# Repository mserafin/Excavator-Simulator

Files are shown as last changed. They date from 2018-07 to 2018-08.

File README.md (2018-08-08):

Excavator simulator
=====

It is an excavator simulator integrated with the game `DIG IT! - A Digger Simulator`, but can be easily integrated with another game.

[Link to the video](https://youtu.be/R2LVpZUrTIc)

The code was created for the needs of my eight-year-old son who is a huge fan of construction machinery.

The whole architecture was based on the Arduino Pro Micro microcontroller, which has a USB 2.0 interface thanks to which the driver can be seen as a USB device. In my case, this allowed me to simulate pressing a combination of keys on the keyboard.

The simulator has been equipped with: four analog joysticks that realistically reflect the physics of machine motion,
ignition switch to run the board, 2x16 LCD display with I2C interfac, which in the first assumption was supposed to show speed and basic parameters, but the game manufacturer did not foresee the possibility of writing modifications. The simulator has also been equipped with six Arcade buttons with backlight to control additional functions, eg turning on the radio, lights, etc. Arduino does not have enough pins, so the simulator has two PCF8574 integrated circuits, thanks to which we obtained an additional 16 digital pins.

Sketch

## License

This project is licensed under the MIT License - see the [LICENSE](LICENSE.md) file for details

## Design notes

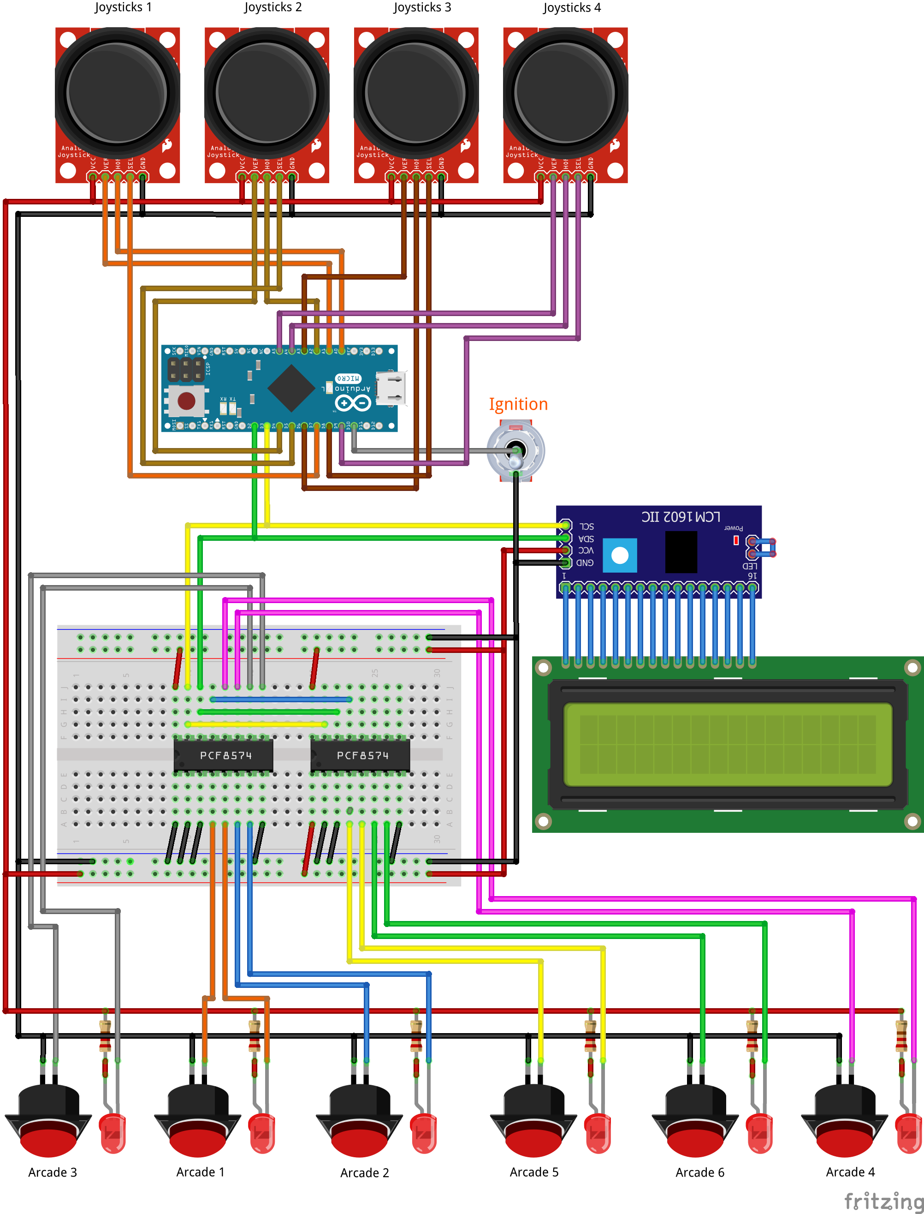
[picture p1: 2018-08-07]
sketch.png

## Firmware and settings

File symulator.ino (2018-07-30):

#include <Keyboard.h>
#include "Expander.h"
#include "Ignition.h"
#include "Display.h"
#include "Axis.h"
#include "Button.h"
#include "ButtonArray.h"
#include "AxisArray.h"
//#include "Mouse.h"

const bool DEBUG = 0;

const int IGNITION_PIN = 10;
const int RANGE_AXIS = 10;
const int COUNT_AXLES = 8;
const int COUNT_SWITCHES = 10;
const int COUNT_LEDS = 6;
const unsigned long RESPONSE_DELAY = 500UL;
const unsigned long DISPLAY_DELAY = 1500UL;

bool buttonAxisA1IsActive = false;
bool buttonAxisA2IsActive = false;

unsigned long lastDisplayMillis;

Display lcd;
Expander expander1;
Expander expander2;
Ignition ignition;
ButtonArray buttonArray = ButtonArray(COUNT_SWITCHES);
AxisArray axisArray = AxisArray(COUNT_AXLES);

enum Simulator {
  EXCAVATORS,
  FARMING
};

struct ShortcutsAxis {
  char KEY_JOYSTICK_UP;
  char KEY_JOYSTICK_DOWN;
  char KEY_JOYSTICK_LEFT;
  char KEY_JOYSTICK_RIGHT;
  char KEY_JOYSTICK_SWITCH;
};

struct Joysticks {
  ShortcutsAxis Joysticks1;
  ShortcutsAxis Joysticks2;
  ShortcutsAxis Joysticks3;
  ShortcutsAxis Joysticks4;
} Mapping[2] = {
  {
    {KEY_UP_ARROW, KEY_DOWN_ARROW, KEY_LEFT_ARROW, KEY_RIGHT_ARROW},
    {'a', 'q', 'k', 'i'},
    {'w', 's'},
    {'e', 'd', 'r', 'f'}
  },
  {
    {'w', 's', 'a', 'd'}
  }
};

struct DebugAxis {
  String axisName;
  int axisValue;
};

Simulator simulator = EXCAVATORS;

void setup() {
  setupIgnition();
  setupExpander();
  setupArcadeLed();
  setupOutput();
  setupDisplay();
  setupSwitch();
  setupAxis();
}

void loop() {
  inspectIgnition();
  inspectExpander();
  inspectSwitch();
  inspectAxis();

  if (checkDisplayUpdate()) {
    lcd.display("Symulator!", true, 0, 0);
    lcd.display("Milosz", false, 0, 1);
  }
}

void setupIgnition() {
  ignition.begin(IGNITION_PIN, ignitionOnChangeStatus);
}

void setupExpander() {
  expander1.begin(0x20);
  expander2.begin(0x21);
}

void setupArcadeLed() {
  struct Config {
    byte pin;
    Expander *expander;
  } leds[COUNT_LEDS] = {
    {1, &expander1},
    {3, &expander1},
    {5, &expander1},
    {7, &expander1},
    {1, &expander2},
    {3, &expander2}
  };

  for (byte i = 0; i < COUNT_LEDS; i++) {
    Config &config = leds[i];
    config.expander->pinMode(config.pin, OUTPUT);
    config.expander->digitalWrite(config.pin, HIGH);
  }
}

void setupOutput() {
  if (!DEBUG) {
    Keyboard.begin();
    //Mouse.begin();
    return;
  }

  while (!Serial);
  Serial.begin(115200);
}

void setupDisplay() {
  lcd.begin(16, 2);
}

void setupSwitch() {
  struct Config {
    byte pin;
    Expander *expander;
    void (*action)(bool state);
  } buttons[COUNT_SWITCHES] = {
    {5, NULL, &SwitchJoystickD5},
    {7, NULL, &SwitchJoystickD7},
    {8, NULL, &SwitchJoystickD8},
    {9, NULL, &SwitchJoystickD9},
    {0, &expander1, &SwitchArcadeE1D0},
    {2, &expander1, &SwitchArcadeE1D2},
    {4, &expander1, &SwitchArcadeE1D4},
    {6, &expander1, &SwitchArcadeE1D6},
    {0, &expander2, &SwitchArcadeE2D0},
    {2, &expander2, &SwitchArcadeE2D2}
  };

  for (byte i = 0; i < COUNT_SWITCHES; i++) {
    Config &config = buttons[i];
    Button button;

    if (config.expander != NULL) {
      button.begin(config.pin, config.expander);
    } else {
      button.begin(config.pin);
    }
    button.onClick = *config.action;
    buttonArray.append(button);
  }
}

void setupAxis() {
  struct Config {
    byte pin;
    void (*action)(int key);
  } Axises[COUNT_AXLES] = {
    {A0, &AxisA0},
    {A1, &AxisA1},
    {A2, &AxisA3},
    {A3, &AxisA4},
    {A4, &AxisA7},
    {A5, &AxisA6},
    {A6, &AxisA2},
    {A7, &AxisA5}
  };

  for (byte i = 0; i < COUNT_AXLES; i++) {
    Config &config = Axises[i];
    Axis axis = Axis(RANGE_AXIS, RESPONSE_DELAY);
    axis.begin(config.pin, *config.action);
    axisArray.append(axis);
  }
}

void inspectIgnition() {
  ignition.refresh();
}

void inspectExpander() {
  expander1.refresh();
  expander2.refresh();
}

void inspectSwitch() {
  buttonArray.refresh();
}

void inspectAxis() {
  axisArray.refresh();
}

void ignitionOnChangeStatus() {
  lcd.display("Wlacz zaplon!");
}

bool checkDisplayUpdate() {
  unsigned long currentMillis = millis();
  if ((currentMillis - lastDisplayMillis) > DISPLAY_DELAY) {
    lastDisplayMillis = currentMillis;
    return true;
  }
  return false;
}

void AxisA0(int reading) {
  DebugAxis debug = {__PRETTY_FUNCTION__, reading};
  ShortcutsAxis shortcut = Mapping[simulator].Joysticks1;
  char key;

  switch (simulator) {
    case EXCAVATORS:
      key = reading > 0 ? shortcut.KEY_JOYSTICK_RIGHT : shortcut.KEY_JOYSTICK_LEFT;

      if (buttonAxisA1IsActive) {
        append(KEY_LEFT_CTRL, false, debug);
      }
      append(key, true, debug);
      break;
    case FARMING:
      key = reading > 0 ? shortcut.KEY_JOYSTICK_LEFT : shortcut.KEY_JOYSTICK_RIGHT;
      append(key, true, debug);
      break;
  }
}

void AxisA1(int reading) {
  DebugAxis debug = {__PRETTY_FUNCTION__, reading};
  ShortcutsAxis shortcut = Mapping[simulator].Joysticks1;

  switch (simulator) {
    case EXCAVATORS:
    case FARMING:
      char key = reading > 0 ? shortcut.KEY_JOYSTICK_UP : shortcut.KEY_JOYSTICK_DOWN;
      append(key, true, debug);
      break;
  }
}

void AxisA2(int reading) {
  DebugAxis debug = {__PRETTY_FUNCTION__, reading};
  ShortcutsAxis shortcut = Mapping[simulator].Joysticks2;

  if (simulator == EXCAVATORS) {
    char key = reading > 0 ? shortcut.KEY_JOYSTICK_UP : shortcut.KEY_JOYSTICK_DOWN;

    if (buttonAxisA2IsActive) {
      key = reading > 0 ? shortcut.KEY_JOYSTICK_LEFT : shortcut.KEY_JOYSTICK_RIGHT;
    }

    append(key, true, debug);
    return;
  }
}

void AxisA3(int reading) {
  DebugAxis debug = {__PRETTY_FUNCTION__, reading};
  ShortcutsAxis shortcut = Mapping[simulator].Joysticks2;
  //append('x', debug);
}

void AxisA4(int reading) {
  DebugAxis debug = {__PRETTY_FUNCTION__, reading};
  ShortcutsAxis shortcut = Mapping[simulator].Joysticks3;

  if (simulator == EXCAVATORS) {
    char key = reading > 0 ? shortcut.KEY_JOYSTICK_UP : shortcut.KEY_JOYSTICK_DOWN;
    append(key, true, debug);
    return;
  }
}

void AxisA5(int reading) {
  DebugAxis debug = {__PRETTY_FUNCTION__, reading};
  ShortcutsAxis shortcut = Mapping[simulator].Joysticks3;
  //append('x', debug);
}

void AxisA6(int reading) {
  DebugAxis debug = {__PRETTY_FUNCTION__, reading};
  ShortcutsAxis shortcut = Mapping[simulator].Joysticks4;

  if (simulator == EXCAVATORS) {
    char key = reading > 0 ? shortcut.KEY_JOYSTICK_UP : shortcut.KEY_JOYSTICK_DOWN;
    append(key, true, {__PRETTY_FUNCTION__, reading});
    return;
  }
}

void AxisA7(int reading) {
  DebugAxis debug = {__PRETTY_FUNCTION__, reading};
  ShortcutsAxis shortcut = Mapping[simulator].Joysticks4;

  if (simulator == EXCAVATORS) {
    char key = reading > 0 ? shortcut.KEY_JOYSTICK_LEFT : shortcut.KEY_JOYSTICK_RIGHT;
    append(key, true, debug);
    return;
  }
}

void SwitchJoystickD5(bool state) {
  buttonAxisA2IsActive = state;
}

void SwitchJoystickD7(bool state) {
  buttonAxisA1IsActive = state;
}

void SwitchJoystickD8(bool state) {
  //Serial.print("SwitchD8: ");
  //Serial.println(state);
}

void SwitchJoystickD9(bool state) {
  //Serial.print("SwitchD9: ");
  //Serial.println(state);
}

void SwitchArcadeE1D0(bool state) {
  //button.expander->blinkAsync(button.pin + 1, 2, 1000UL);
  //button.expander->toggleAsync(button.pin + 1);

  expander1.blinkAsync(1, 2, 1000UL);

  //Serial.print("SwitchArcadeE1D0: ");
  //Serial.println(state);
}

void SwitchArcadeE1D2(bool state) {
  expander1.toggleAsync(3);

  //Serial.print("SwitchArcadeE1D2: ");
  //Serial.println(state);
}

void SwitchArcadeE1D4(bool state) {
  expander1.blinkAsync(5, 2, 1000UL);

  //Serial.print("SwitchArcadeE1D4: ");
  //Serial.println(state);
}

void SwitchArcadeE1D6(bool state) {
  expander1.toggleAsync(7);

  //Serial.print("SwitchArcadeE1D6: ");
  //Serial.println(state);
}

void SwitchArcadeE2D0(bool state) {
  expander2.toggleAsync(1);

  //Serial.print("SwitchArcadeE2D0: ");
  //Serial.println(state);
}

void SwitchArcadeE2D2(bool state) {
  expander2.toggleAsync(3);

  //Serial.print("SwitchArcadeE2D2: ");
  //Serial.println(state);
}

void append(char key, bool push, DebugAxis debug) {
  if (!DEBUG) {
    Keyboard.press(key);

    if (push) {
      //delay(100);
      Keyboard.releaseAll();
    }
    return;
  }

  Serial.print(debug.axisName);
  Serial.print(", value: ");
  Serial.print(debug.axisValue);
  Serial.print(", key: ");
  Serial.println(key);
}

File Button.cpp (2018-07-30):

#include "Button.h"

Button::Button() {}

void Button::begin(uint8_t pin) {
  this->pin = pin;
  pinMode(pin, INPUT_PULLUP);
}

void Button::begin(uint8_t pin, Expander *expander) {
  this->pin = pin;
  this->expander = expander;
  this->expander->pinMode(pin, INPUT_PULLUP);
}

uint8_t Button::getPin() const {
  return pin;
}

void Button::refresh() {
  uint8_t state = expander != NULL ?
                  expander->digitalRead(pin) : digitalRead(pin);

  if (state != story.lastState && state == LOW) {
    story.state = !story.state;

    if (onClick != NULL) {
      onClick(story.state);
    }
  }
  story.lastState = state;
}
